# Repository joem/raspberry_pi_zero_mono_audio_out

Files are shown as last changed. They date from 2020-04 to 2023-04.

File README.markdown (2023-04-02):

Raspberry Pi Zero Mono Audio Output
===================================

> :warning: _NOTE: This board hasn’t been tested yet. It’s simple enough that I’m fairly certain it’s OK, but in case it’s not, this is why. After I test it, I’ll remove this note._

There are already some other RPi Zero (or Zero W) audio output pcbs available, but this one was designed specifically with several goals in mind:

- mono
- through hole
- fits inside my RPi Zero case
- uses a PJ302M jack to mount it to the case
- decently documented

It’s based on [a circuit from tinkernut](http://www.tinkernut.com/2017/04/adding-audio-output-raspberry-pi-zero-tinkernut-workbench/) though I’m not sure if they originated it (it’s just a passive filter, after all). See that tinkernut page for more info about setting up the RPi to work with it. And if that page ever disappears, feel free to google for something like “rpi zero pwm audio” since there are many articles about how to set that up. I used through-hole components because I didn’t have all the right parts in SMD and it's small enough for my needs. There are no mounting holes because it’s intended to be panel-mounted via the jack.

This was designed as a KiCad project, but if you want to fabricate a PCB you don't need KiCad since the gerbers are in the gerbers folder. Also, there's a PDF schematic in the pdfs directory. And if you just want to order PCBs, [there's an OSHPark project](https://oshpark.com/shared_projects/ILTMx6KX).

Opening the KiCad project requires KiCad 6 at a minimum. I've removed the old KiCad 5 files.

BOM:

- R1 = 270R
- R2 = 150R
- C1 = 10uF electrolytic, 2.5mm lead spacing
- C2 = 33nF ceramic, 5mm lead spacing (tinkernut’s page says “0.33uF” but other similar schematics say 33nF)
- J1 = PJ302M 3.5mm mono jack
- J2 = 1x2 pin header (I use right angle)

The lead spacing for the capacitors is not a strict requirement, since you can always bend the leads in or out a bit if you’re close. When shopping for the electrolytic cap, be aware of its size, especially if you’re going to be putting this in a tight space like I am. (I prefer using the Panasonic ECE-A1VKS100 since it's nice and short. Mouser part #: 667-ECE-A1VKS100)

Render from KiCad:

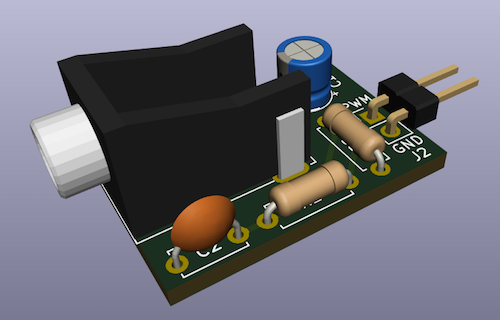
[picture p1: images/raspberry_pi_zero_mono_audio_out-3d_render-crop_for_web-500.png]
Raspbery Pi Zero Mono Audio Output 3D Render


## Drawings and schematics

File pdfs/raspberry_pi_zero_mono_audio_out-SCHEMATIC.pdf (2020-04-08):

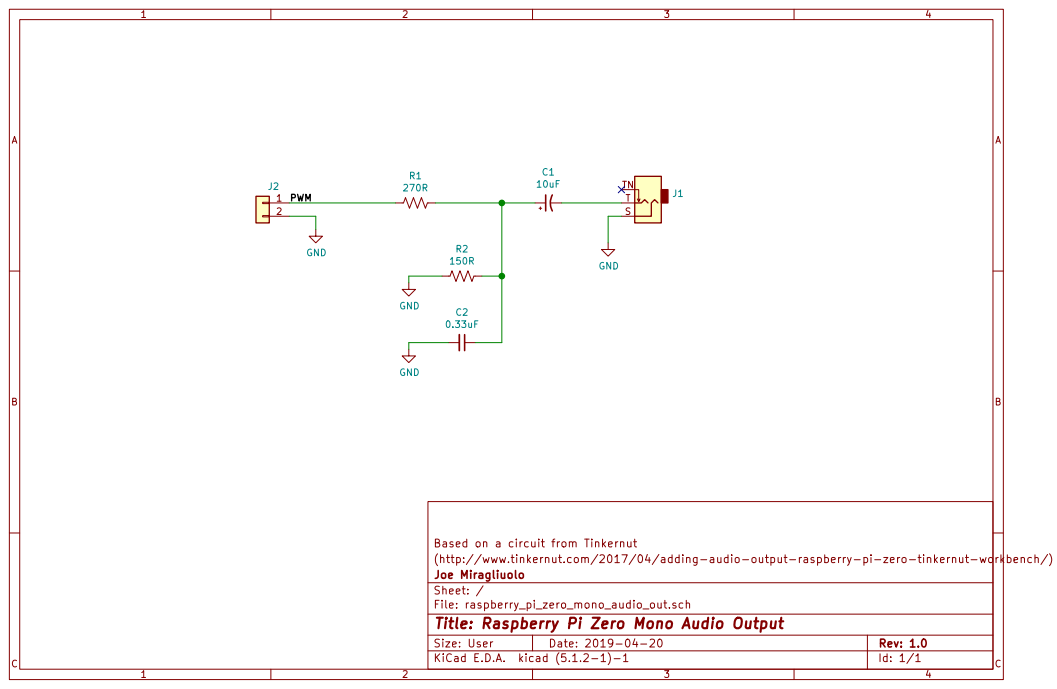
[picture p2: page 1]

(http://www.tinkernut.com/2017/04/adding-audio-output-raspberry-pi-zero-tinkernut-workbench/) Based on a circuit from Tinkernut R1

File: raspberry_pi_zero_mono_audio_out.sch Sheet: / Joe Miragliuolo

Id: 1/1 Title: Raspberry Pi Zero Mono Audio Output

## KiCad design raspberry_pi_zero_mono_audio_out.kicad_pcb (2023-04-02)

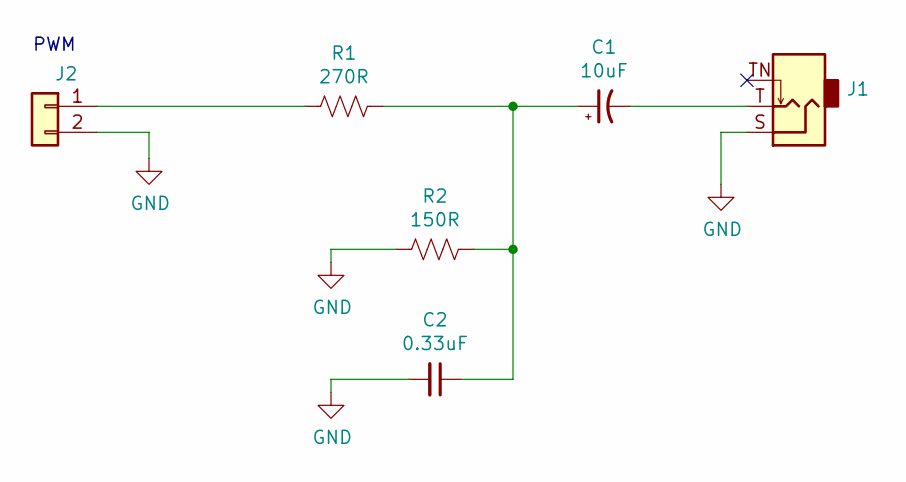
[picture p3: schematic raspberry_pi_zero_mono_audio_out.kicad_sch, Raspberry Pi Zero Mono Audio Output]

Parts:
C1: 10uF; CP_Radial_D5.0mm_P2.50mm
C2: 0.33uF; C_Disc_D5.0mm_W2.5mm_P5.00mm
J1: AudioJack2_SwitchT; Jack_3.5mm_QingPu_WQP-PJ302M_Horizontal
J2: Conn_01x02; PinHeader_1x02_P2.54mm_Vertical
R1: 270R; R_Axial_DIN0207_L6.3mm_D2.5mm_P7.62mm_Horizontal
R2: 150R; R_Axial_DIN0207_L6.3mm_D2.5mm_P7.62mm_Horizontal

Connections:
/PWM: J2.1, R1.2
GND: C2.2, J1.S, J2.2, R2.2
unnamed: C1.1, C2.1, R1.1, R2.1
unnamed: C1.2, J1.T

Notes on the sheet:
PWM

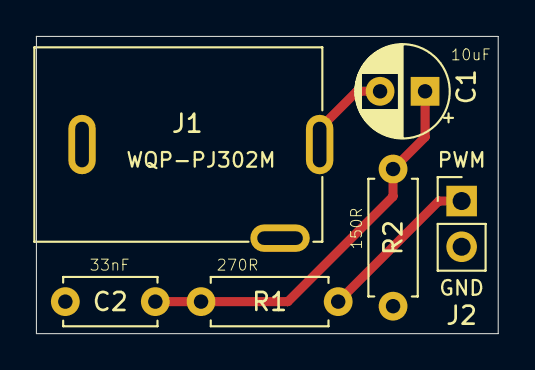
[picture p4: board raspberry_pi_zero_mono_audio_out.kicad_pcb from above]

Board: 2 copper layers, 25.7 x 16.5 mm, 6 parts (0 on the bottom side), 4 nets.

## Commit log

2020-04-08 Add rendered image to readme
    [raspberry_pi_zero_mono_audio_out.kicad_pcb]
2020-04-22 Update silkscreen with github URL
    [raspberry_pi_zero_mono_audio_out-B_Cu.gbl, raspberry_pi_zero_mono_audio_out-B_Mask.gbs, raspberry_pi_zero_mono_audio_out-B_SilkS.gbo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]
2023-04-02 Update project to kicad 6+
    [raspberry_pi_zero_mono_audio_out.kicad_pcb, raspberry_pi_zero_mono_audio_out.kicad_sch, raspberry_pi_zero_mono_audio_out.sch]
